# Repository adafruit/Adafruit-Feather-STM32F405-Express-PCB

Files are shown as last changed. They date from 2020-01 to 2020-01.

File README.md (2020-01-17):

## Adafruit Adafruit Feather STM32F405 Express PCB

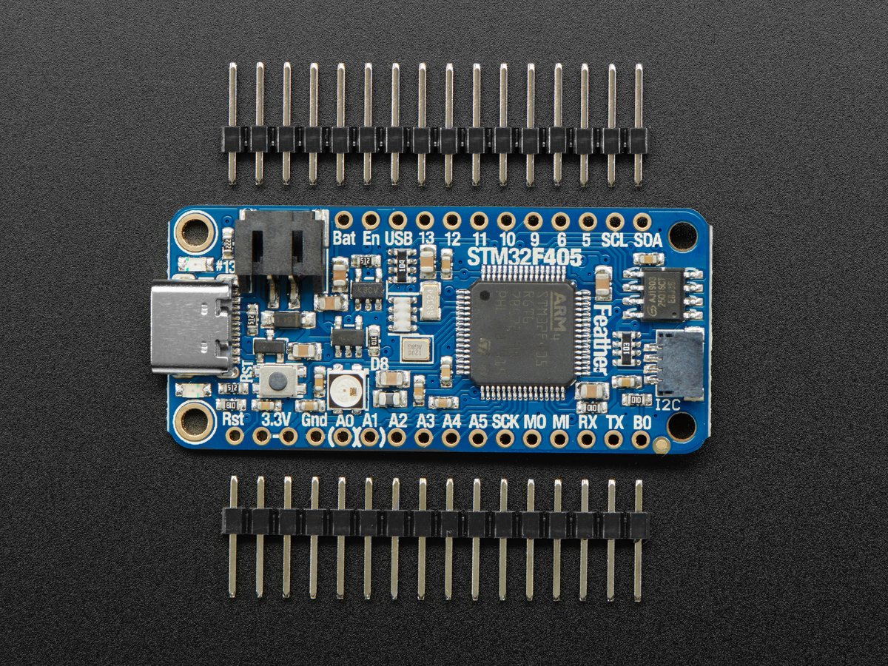
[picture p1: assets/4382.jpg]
<a href="http://www.adafruit.com/products/4382"><br/>
Click here to purchase one from the Adafruit shop</a>

PCB files for the Adafruit Adafruit Feather STM32F405 Express. 

Format is EagleCAD schematic and board layout
* https://www.adafruit.com/product/4382

### Description

ST takes flight in this upcoming Feather board. The new STM32F405 Feather (video) that we designed runs CircuitPython at a blistering 168MHz – our fastest CircuitPython board ever! We put a STEMMA QT / Qwiic port on the end, so you can really easily plug and play I2C sensors.

This Feather has lots of goodies:

* STM32F405 Cortex M4 with FPU and 1MB Flash, 168MHz speed
* 192KB RAM total - 128 KB RAM for general usage + 64 KB program-only/cache RAM
* 3.3V logic, but almost all pins are 5V compliant!
* USB C power and data - our first USB C Feather!
* LiPo connector and charger
* SD socket on the bottom, connected to SDIO port
* 2 MB SPI Flash chip
* Built in NeoPixel indicator
* I2C, UART, GPIO, ADCs, DACs
* Qwiic/STEMMA-QT connector for fast I2C connectivity
* We use the built-in USB DFU bootloader to load firmware. It does not come with a UF2 bootloader.

With CircuitPython basics running on this board, it's fast to get all our drivers working, then use the built in plotter in Mu to instantly get sensor data displaying within 3 minutes of unboxing.

You can use MicroPython, CircuitPython or Arduino IDE with this board, with some caveats. This board and chipset is new so expect rapid developments and updates!

* CircuitPython support is under development. We have digital IO, analog in/out, I2C, SPI, PWM working so far and more on the way. For example, the SDIO SD card is not yet supported natively. DisplayIO is also not yet supported.
* Arduino is supported through STM32duino. There's no auto-reset bootloader support yet so you have to pull the BOOT0 pin high and manually reset before uploading. That said, STM32 support is really good, and we were able to run just about every sketch we tried.
* MicroPython support is very solid but Adafruit does not provide MicroPython libraries for sensors!

We tested this in Arduino STM32duino with all our FeatherWings and only the RFM69/RFM9x libraries did not work (they are very platform specific). Its an extraordinarily fast Feather, and our first foray into STM32 - very exciting!

### License

Adafruit invests time and resources providing this open source design, please support Adafruit and open-source hardware by purchasing products from [Adafruit](https://www.adafruit.com)!

Designed by Limor Fried/Ladyada for Adafruit Industries.

Creative Commons Attribution/Share-Alike, all text above must be included in any redistribution. 
See license.txt for additional details.

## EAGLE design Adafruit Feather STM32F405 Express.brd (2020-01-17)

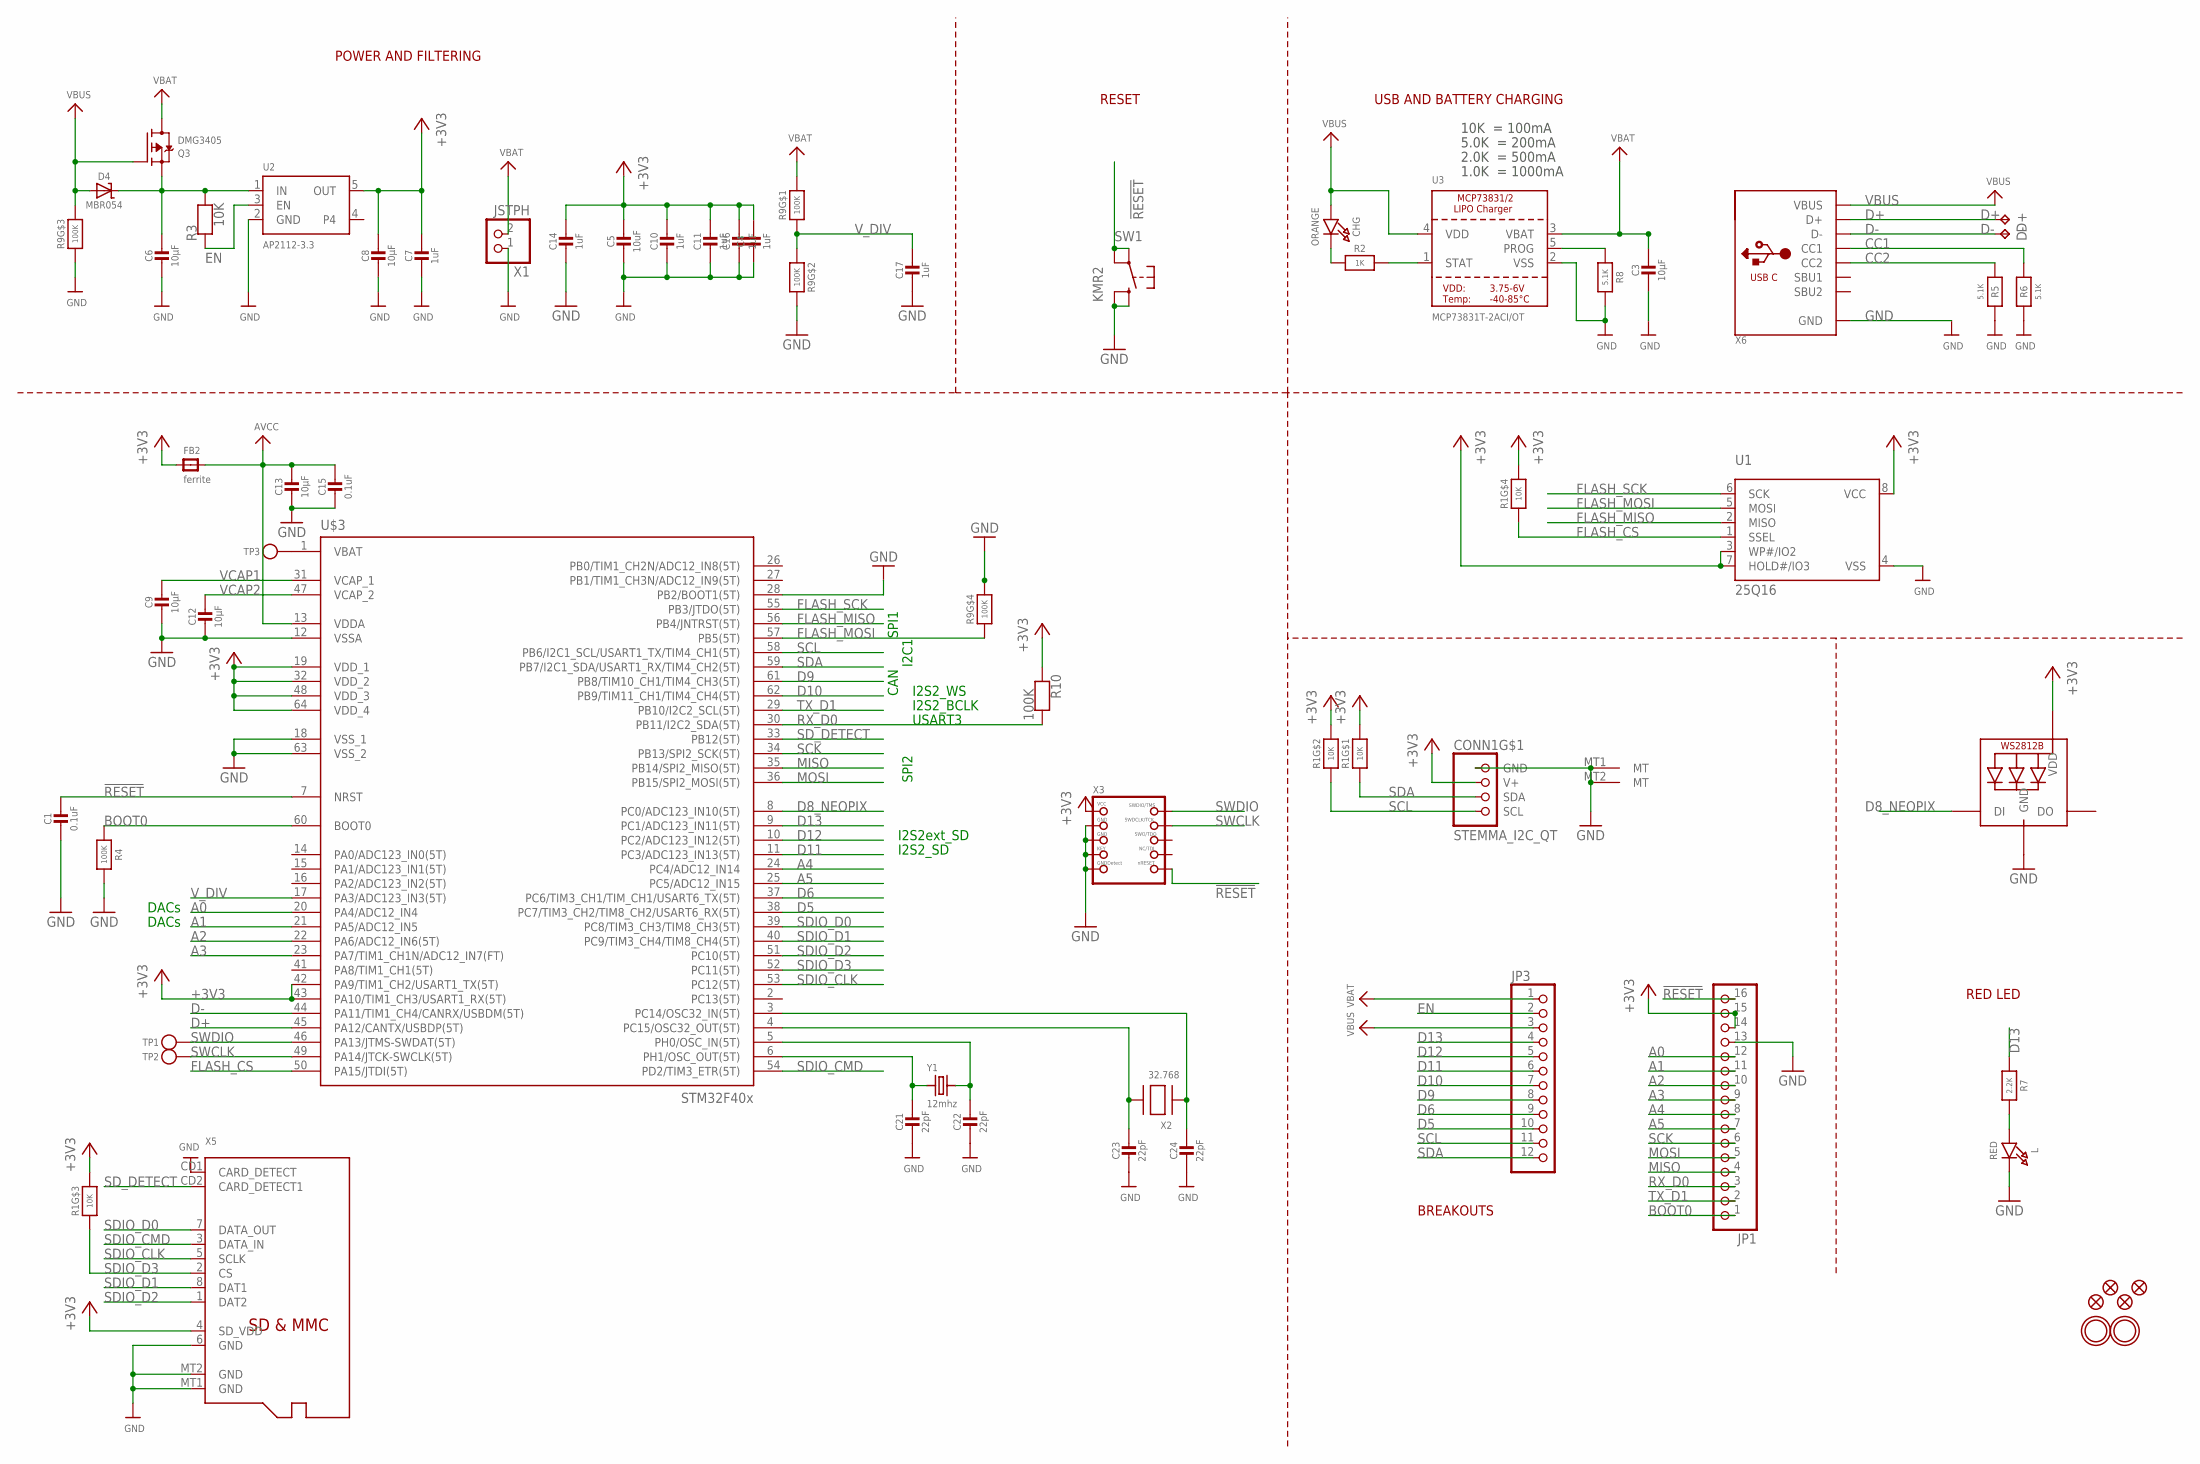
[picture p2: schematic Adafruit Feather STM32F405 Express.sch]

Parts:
C1, C15: 0.1uF; 0603-NO
C2: 22pF; RESPACK_4X0603
C3, C6, C8, C9, C12, C13: 10µF; 0805-NO
C4, C7, C10, C11, C14, C16, C17: 1uF; 0603-NO
C5: 10uF; 0805-NO
CHG: ORANGE; CHIPLED_0805_NOOUTLINE
CONN1: STEMMA_I2C_QT; JST_SH4
D4: MBR054; SOD-123
D+: TPB1,27; B1,27
D-: TPB1,27; B1,27
FB2: ferrite; 0805-NO
JP1: HEADER-1X16ROUND; 1X16_ROUND
JP3: HEADER-1X12; 1X12_ROUND
L: RED; CHIPLED_0805_NOOUTLINE
LED1: WS2812B3535; LED3535
Q3: DMG3405; SOT23-R
R1: 10K; RESPACK_4X0603_NO
R2: 1K; 0603-NO
R3: 10K; 0603-NO
R4, R10: 100K; 0603-NO
R5, R6, R8: 5.1K; 0603-NO
R7: 2.2K; 0603-NO
R9: 100K; RESPACK_4X0603_NO
SW1: KMR2; BTN_KMR2_4.6X2.8
TP1, TP2, TP3: TESTPOINTROUND1.5MM; TESTPOINT_ROUND_1.5MM
U1: 25Q16; SOIC8_150MIL
U2: AP2112-3.3; SOT23-5
U3: MCP73831T-2ACI/OT; SOT23-5
U$3: STM32F405R; TQFP64
U$5, U$34, U$35, U$37: FIDUCIAL_1MM
U$31, U$32: MOUNTINGHOLE2.5; MOUNTINGHOLE_2.5_PLATED
X1: JSTPH; JSTPH2
X2: 32.768; XTAL3215
X3: JTAG-CORTEX; 2X05_1.27MM_SMT
X5: MICROSD
X6: USB_C; USB_C_CUSB31-CFM2AX-01-X
Y1: 12mhz; CRYSTAL_2.5X2

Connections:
!RESET: C1.1, JP1.16, SW1.A, SW1.A' (P1), U$3.7 (NRST), X3.10 (NRESET)
+3V3: C4.1, C5.1, C7.1, C8.1, C10.1, C11.1, C14.1, C16.1, CONN1.2 (V+), FB2.1, JP1.14, JP1.15, LED1.2 (VDD), R1.5 (2), R1.6 (2), R1.7 (2), R1.8 (2), R10.1, U1.3 (WP#/IO2), U1.7 (HOLD#/IO3), U1.8 (VCC), U2.5 (OUT), U$3.19 (VDD_1), U$3.32 (VDD_2), U$3.42 (PA9/TIM1_CH2/USART1_TX(5T)), U$3.43 (PA10/TIM1_CH3/USART1_RX(5T)), U$3.48 (VDD_3), U$3.64 (VDD_4), X3.1 (VCC), X5.4 (SD_VDD)
A0: JP1.12, U$3.20 (PA4/ADC12_IN4)
A1: JP1.11, U$3.21 (PA5/ADC12_IN5)
A2: JP1.10, U$3.22 (PA6/ADC12_IN6(5T))
A3: JP1.9, U$3.23 (PA7/TIM1_CH1N/ADC12_IN7(FT))
A4: JP1.8, U$3.24 (PC4/ADC12_IN14)
A5: JP1.7, U$3.25 (PC5/ADC12_IN15)
AVCC: C13.1, C15.1, FB2.2, U$3.13 (VDDA)
BATTERY: TP3.P$1, U$3.1 (VBAT)
BOOT0: JP1.1, R4.1, U$3.60 (BOOT0)
CC1: R6.2, X6.A5 (CC1)
CC2: R5.2, X6.B5 (CC2)
D5: JP3.10, U$3.38 (PC7/TIM3_CH2/TIM8_CH2/USART6_RX(5T))
D6: JP3.9, U$3.37 (PC6/TIM3_CH1/TIM_CH1/USART6_TX(5T))
D8_NEOPIX: LED1.1 (DI), U$3.8 (PC0/ADC123_IN10(5T))
D9: JP3.8, U$3.61 (PB8/TIM10_CH1/TIM4_CH3(5T))
D10: JP3.7, U$3.62 (PB9/TIM11_CH1/TIM4_CH4(5T))
D11: JP3.6, U$3.11 (PC3/ADC123_IN13(5T))
D12: JP3.5, U$3.10 (PC2/ADC123_IN12(5T))
D13: JP3.4, R7.1, U$3.9 (PC1/ADC123_IN11(5T))
D+: D+.TP, U$3.45 (PA12/CANTX/USBDP(5T)), X6.A6 (D+), X6.B6 (D+)
D-: D-.TP, U$3.44 (PA11/TIM1_CH4/CANRX/USBDM(5T)), X6.A7 (D-), X6.B7 (D-)
EN: JP3.2, R3.1, U2.3 (EN)
FLASH_CS: R1.4 (1), U1.1 (SSEL), U$3.50 (PA15/JTDI(5T))
FLASH_MISO: U1.2 (MISO), U$3.56 (PB4/JNTRST(5T))
FLASH_MOSI: R9.4 (1), U1.5 (MOSI), U$3.57 (PB5(5T))
FLASH_SCK: U1.6 (SCK), U$3.55 (PB3/JTDO(5T))
GND: C1.2, C2.5 (2), C2.6 (2), C2.7 (2), C2.8 (2), C3.2, C4.2, C5.2, C6.2, C7.2, C8.2, C9.2, C10.2, C11.2, C12.2, C13.2, C14.2, C15.2, C16.2, C17.2, CONN1.1 (GND), CONN1.MT1 (MT), CONN1.MT2 (MT), JP1.13, L.C, LED1.4 (GND), R4.2, R5.1, R6.1, R8.2, R9.3 (1), R9.5 (2), R9.7 (2), SW1.B (S), SW1.B' (S1), U1.4 (VSS), U2.2 (GND), U3.2 (VSS), U$3.12 (VSSA), U$3.18 (VSS_1), U$3.28 (PB2/BOOT1(5T)), U$3.63 (VSS_2), X1.1, X3.3 (GND), X3.5 (GND), X3.7 (KEY), X3.9 (GNDDETECT), X5.6 (GND), X5.CD1 (CARD_DETECT), X5.MT1 (GND), X5.MT2 (GND), X6.A1B12 (GND), X6.B1A12 (GND)
MISO: JP1.4, U$3.35 (PB14/SPI2_MISO(5T))
MOSI: JP1.5, U$3.36 (PB15/SPI2_MOSI(5T))
unnamed: CHG.C, R2.1
unnamed: L.A, R7.2
unnamed: R2.2, U3.1 (STAT)
unnamed: R8.1, U3.5 (PROG)
unnamed: C2.4 (1), U$3.3 (PC14/OSC32_IN(5T)), X2.P$1
unnamed: C2.2 (1), U$3.5 (PH0/OSC_IN(5T)), Y1.3 (2)
unnamed: C2.3 (1), U$3.4 (PC15/OSC32_OUT(5T)), X2.P$2
unnamed: C2.1, U$3.6 (PH1/OSC_OUT(5T)), Y1.1
RX_D0: JP1.3, R10.2, U$3.30 (PB11/I2C2_SDA(5T))
SCK: JP1.6, U$3.34 (PB13/SPI2_SCK(5T))
SCL: CONN1.4 (SCL), JP3.11, R1.2 (1), U$3.58 (PB6/I2C1_SCL/USART1_TX/TIM4_CH1(5T))
SDA: CONN1.3 (SDA), JP3.12, R1.1, U$3.59 (PB7/I2C1_SDA/USART1_RX/TIM4_CH2(5T))
SDIO_CLK: U$3.53 (PC12(5T)), X5.5 (SCLK)
SDIO_CMD: U$3.54 (PD2/TIM3_ETR(5T)), X5.3 (DATA_IN)
SDIO_D0: U$3.39 (PC8/TIM3_CH3/TIM8_CH3(5T)), X5.7 (DATA_OUT)
SDIO_D1: U$3.40 (PC9/TIM3_CH4/TIM8_CH4(5T)), X5.8 (DAT1)
SDIO_D2: U$3.51 (PC10(5T)), X5.1 (DAT2)
SDIO_D3: R1.3 (1), U$3.52 (PC11(5T)), X5.2 (CS)
SD_DETECT: U$3.33 (PB12(5T)), X5.CD2 (CARD_DETECT1)
SWCLK: TP2.P$1, U$3.49 (PA14/JTCK-SWCLK(5T)), X3.4 (SWDCLK)
SWDIO: TP1.P$1, U$3.46 (PA13/JTMS-SWDAT(5T)), X3.2 (SWDIO)
TX_D1: JP1.2, U$3.29 (PB10/I2C2_SCL(5T))
VBAT: C3.1, JP3.1, Q3.3 (D), R9.8 (2), U3.3 (VBAT), X1.2
VBUS: CHG.A, D4.A, JP3.3, Q3.1 (G), R9.6 (2), U3.4 (VDD), X6.A4B9 (VBUS), X6.B4A9 (VBUS)
VCAP1: C9.1, U$3.31 (VCAP_1)
VCAP2: C12.1, U$3.47 (VCAP_2)
VHI: C6.1, D4.C, Q3.2 (S), R3.2, U2.1 (IN)
V_DIV: C17.1, R9.1, R9.2 (1), U$3.17 (PA3/ADC123_IN3(5T))

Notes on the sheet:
POWER AND FILTERING
RESET
10K = 100mA
5.0K = 200mA
2.0K = 500mA
1.0K = 1000mA
USB AND BATTERY CHARGING
BREAKOUTS
RED LED
SPI1
SPI2
USART3
DACs
I2C1
I2S2_WS
I2S2_BCLK
I2S2_SD
I2S2ext_SD
CAN

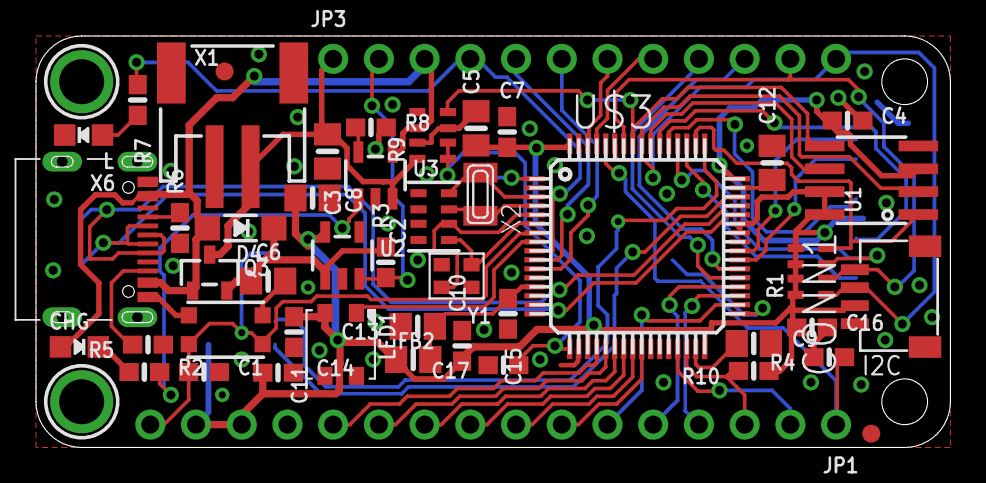
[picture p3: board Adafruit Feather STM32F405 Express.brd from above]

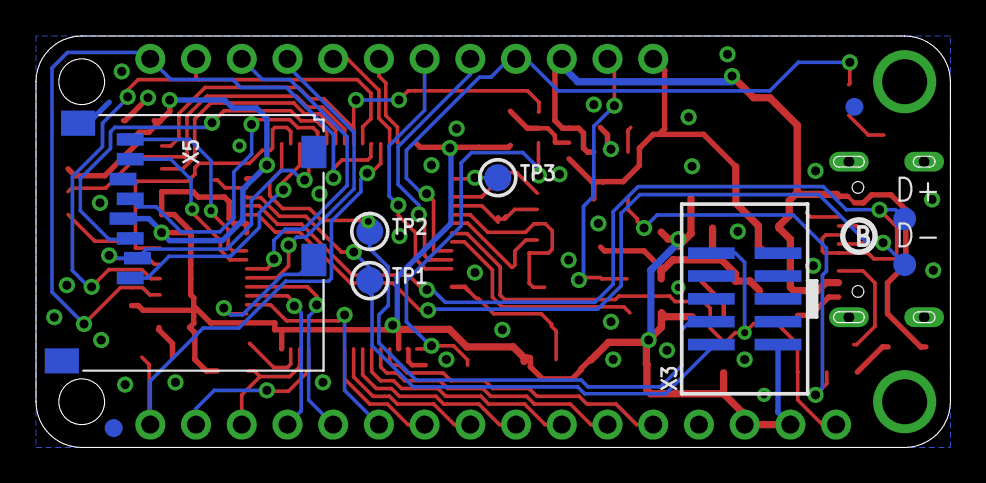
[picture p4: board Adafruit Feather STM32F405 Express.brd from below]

Board: 2 copper layers, 50.8 x 22.9 mm, 61 parts (11 on the bottom side), 59 nets.

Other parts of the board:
U$13: PCBFEAT-REV-040
U$24: FEATHER_STM32F405_TOP
U$40: FEATHER_STM32F405_BOT

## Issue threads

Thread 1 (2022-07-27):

STM32F405 Express, PCB error about SD card detection

dombru54, 2022-07-27:
Hello,

With your STM32F405 Feather Express card, the PB12 pin (cardDetect) is always to 0 (GND).
This is due to a short circuit with the card reader double pin 10
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

Error in the card reader manufacturer's datasheet and red correction
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

With actual PCB, cut ground track with a scalpel, at the edge of the metal case
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

Thanks to make a revision of this board
.

ladyada, 2022-07-27:
thanks for the note - we'll fix this on the next PCB run!

dombru54, 2022-07-27:
Sorry,
The new schema corrected
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

javiBajoCero, 2023-04-13:
Howdy @dombru54 , thanks for your work, i just purchased two feathers from [here](https://www.berrybase.de/es/adafruit-feather-stm32f405-express), and i foudn the same problem with the same solution.

I dont see any Hardware revision markings in my boards, so either berrybase had old stock or this error wasnt fixed yet.

dombru54, 2023-04-14:
@javiBajoCero ,
It is with great pleasure that I welcome your return, my friend.
I also invite you to see another of my work on the Oled feather
https://github.com/adafruit/Adafruit-OLED-FeatherWing-PCB/issues/10
Best regards

dombru54, 2023-04-14:
@javiBajoCero ,
In addition, if you work with STM32CubeIDE, you must modify :
".....\STM32CubeIDE\workspace_1.8.0\project\FATFS\Target\fatfs_platform.c"
````
uint8_t	BSP_PlatformIsDetected(void) {
    uint8_t status = SD_PRESENT;
    /* Check SD card detect pin */
    if(HAL_GPIO_ReadPin(SD_DETECT_GPIO_PORT, SD_DETECT_PIN) != GPIO_PIN_RESET)
    {
        status = SD_NOT_PRESENT;
    }
    /* USER CODE BEGIN 1 */
    /* user code can be inserted here */
    // Correction de l'erreur génèrée dans le code par MX, au dessus
    if(HAL_GPIO_ReadPin(SD_DETECT_GPIO_PORT, SD_DETECT_PIN) == GPIO_PIN_SET){	// carte présente = 1 (SET)
    	status = SD_PRESENT;
    }
    /* USER CODE END 1 */
    return status;

javiBajoCero, 2023-04-14:
Thanks for your advice, i was trying to make SD+SDIO(4bits) work but, two days later, still nothing.

Not STM32 HAL CUbeMX based, not even with arduino
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

I know statistically im messing up something in my code but seeing they missed this SD detection Gpio, im starting to be afraid they didnt tested SD .

If you have any more clues or repos with working code let me know

dombru54, 2023-04-14:
@javiBajoCero ,
All the SDIO 4 bits mode works on the Feather ! but ....
"two days later, still nothing." .... normal ... ;>) .... SDIO is very poorly documented.
I struggled for more than a week before having all the elements !!!
1) SDIO clock is based on USB clock at 48MHz.
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

2) After, you must use a divider with ClockDiv = 3 , especially not another value ... for me
   SDIO_CK = SDIOCLK / (2 + CLKDIV) => SDIO_CK = 48MHz/(2+3) = 9.6 MHz
````
  static void MX_SDIO_SD_Init(void) {
  hsd.Instance = SDIO;
  hsd.Init.ClockEdge = SDIO_CLOCK_EDGE_RISING;
  hsd.Init.ClockBypass = SDIO_CLOCK_BYPASS_DISABLE;
  hsd.Init.ClockPowerSave = SDIO_CLOCK_POWER_SAVE_DISABLE;
  hsd.Init.BusWide = SDIO_BUS_WIDE_1B;
  hsd.Init.HardwareFlowControl = SDIO_HARDWARE_FLOW_CONTROL_DISABLE;
  hsd.Init.ClockDiv = 3; }
````

dombru54, 2023-04-15:
@javiBajoCero ,

3) For good precision, it is more than recommended to use the 2 quartz, therefore the 2 LSE and HSE modes.
````
void SystemClock_Config(void) {
  .......
  RCC_OscInitStruct.OscillatorType = RCC_OSCILLATORTYPE_HSE|RCC_OSCILLATORTYPE_LSE;
  RCC_OscInitStruct.HSEState = RCC_HSE_ON;
  RCC_OscInitStruct.LSEState = RCC_LSE_ON;
  RCC_OscInitStruct.PLL.PLLState = RCC_PLL_ON;
  RCC_OscInitStruct.PLL.PLLSource = RCC_PLLSOURCE_HSE;
  .......

dombru54, 2023-04-15:
@javiBajoCero ,
Feather has a trap about its serigraphy, 2 "Bats" with 2 different functions, one for powering on LiPo connector and the other on backing up the RTC.
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

dombru54, 2023-04-15:
@javiBajoCero ,
4. For the SDIO to work, you must activate the USB pins.
    Here is the complete pinout of my cubeMX project : My sensors board is FlowMotion Breakout on I2C and SPI.
    Magenta pins => not connected to the PCB.
    Orange pins => declared but not used

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

javiBajoCero, 2023-04-15:
Hi @dombru54 , first thanks for all of your tips, they are gold!

I got it to work yesterday, my problems were ;
- the clock divider was too low (resulting SDIO clokc was too fast)
- the SD detect logic needded to be reversed
- fatfs library doesnt like to be breakpointed by the debugger.

About your tips:

1. SDIO clock is based on USB clock at 48MHz.

I see youre using a super old version of cubeMX, why is that?
>In my Cube version i cannot se any SDIO dedicated box in the clock graphic config tool.
I tought the SDIO  was clocked with the APB2 peripheral clock.
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
i am not enabling the USB and SDIO works as expected.

2.After, you must use a divider with ClockDiv = 3 , especially not another value ... for me
>bingo, this was one of the problems i had, apparently SDIO really dislikes being clocked further than 24Mhz
as my APB2 is clocked to 84Mhz by using a divide factor of 4 i get 14Mhz for the SDIO and it works.
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

3.For good precision, it is more than recommended to use the 2 quartz, therefore the 2 LSE and HSE modes.
>I had this present since the start, always HSE (xtal), my last job consisted in 2 painfull years of mitigating the cathastrophic decision someone had using a HSI for automotive CANbus connected systems. (because it worked for them in the lab)

4.4. For the SDIO to work, you must activate the USB pins, maybe to run USB clock.
>Thanks for sharing your design!, i didnt need to enable the USB for my progect to work tough, check it out in here https://github.com/javiBajoCero/featherSDcardTests

dombru54, 2023-04-15:
Hello @javiBajoCero ,
Thanks for sharing your experience.

1. I don't have an old version, it's a copy of web image ... ;>) ...
   the "Clock configuration" is not complete, it lacks sharing modes between HSE and LSE, for example ... but also SDIO clock ...

2. I'm happy for you, Thanks for RM0090, but i'm surprised.
page 1022 :
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

3. HSE is also very important for the PDM bus with microphones (ultrasonic acoustic spectrum aliasing of decimation).

4. Thank you for this surprising information.

Hope to read you soon

dombru54, 2023-04-15:
Hello @javiBajoCero ,

1. see AN3988 : https://www.st.com/resource/en/application_note/an3988-clock-configuration-tool-for-stm32f40xx41xx427x437x-microcontrollers-stmicroelectronics.pdf
   see "Clock configuration tool" STSW-STM32091 : https://www.st.com/en/development-tools/stsw-stm32091.html
   it's an Excel sheet : "STM32F4xx_Clock_Configuration_V1.1.0.xls"

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

SYL

javiBajoCero, 2023-04-16:
Its my first time working with stm32's F4 family, so i was just clicking my way with cubeMx doing all the clock configs.

SDIO is indeed very poorly documented.
It seems SDIO uses indeed two different clocks comming from two different places, one for the APB interface and another for the "adapter".
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

1. see AN3988
>So my guess is , cubeMX is enabling the SDIOCLK somwhere for me.
No clue of where **PLL48CLK** is, there is a lack of consistent naming in these stm ap notes.
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
It looks to me , somewhere, there is a PLL48CLK from which USB and SDIO clocks would come from, USB would only work with sharp 48Mhz so if enabled, all the rest of peripherals whose clock comes from PLL48CLK  will need to work with 48Mhz as well.
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

dombru54, 2023-04-16:
Hello @javiBajoCero ,
In one of your repo first page, you can add our sharing ... a gold mine .... ;>) ...
SYL

dombru54, 2023-04-16:
Hello @javiBajoCero ,
if you like "Feather factor form", you must absolutely see the great "Swan Blues Wireless", STM32L4R5 :
https://blues.io/products/swan/
https://www.hackster.io/news/swan-from-blues-wireless-is-the-most-expandable-feather-compatible-board-to-date-01132f5a0a91
https://github.com/gauteh/swan-stm32l4r5-quickstart
https://blog.adafruit.com/2021/09/30/the-blues-wireless-swan-a-feather-board-based-on-the-stm32l4r5-feather-blueswireless/

Version 1.7 :
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
Multi-layers board, V1.7, it exists Version 3.0 :
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

javiBajoCero, 2023-04-16:
>In one of your repo first page, you can add our sharing ... a gold mine .... ;>) ...

I didnt understood that sorry.

>"Swan Blues Wireless"

this looks very nice!!! i will stick with adafruit feather tough.
I just wanted some hardware to test my code before spending money manufacturing my own thing.

dombru54, 2023-04-16:
Hello @javiBajoCero ,
In one of your repo first page, you can add our sharing ... a gold mine .... ;>) ...

Sorry, most directly, you could insert this issue in the file "readme.md" of https://github.com/javiBajoCero/featherSDcardTests ...
This might help a reader of your repo.

Neopixel ... I understand why : https://www.hackster.io/javier-munoz-saez/coding-your-own-neopixel-driver-baremetal-stm32-b6b4d0
SYS

aspence, 2023-11-28:
Hi all!

Trying to use the SD card on this board over SDIO within ST32duino. We can program the board and get data from an MSA311 over the qic connect, but we can't get SD.begin() to work. Initially, it would hang for a long time at this step (multiple seconds), and then fail. We think we found the letter "B" with a circle around it on the board, suggesting this was a Rev B board with the card detect trace error. We cut that trace with an exacto. Now, it fails much more quickly. Our hypotheses as to the problem are:

1. We are not initializing the library correctly
2. We are not formatting the SD card correctly
3. There is still a wiring error.

Details of each are:
1. Our code is along the lines of
#include <STM32SD.h>

setup:
SD.setDX(PC8,PC9,PC10,PC11);
SD.setCK(PC12);
SD.setCMD(PD2);
if (!SD.begin(PB12)) {  // detect
  Serial.println('failure to init');
  while(1);
}

we are not including a PinName library - but it compiles so I assume that's ok...

2. We have a 120gb SD card. In windows, we erased all partitions and created a single 3.5 gb fat32 partition. we did not alter the partition table.

3. The fact that the boot time/error time changed after we cut the trace suggested it did something, but it still gives an error on startup. We dont have a known good SD card around to try.

It would be very useful to hear from anyone who has gotten this working with code similar to the above for setting the pins, and with just cutting the trace.

If we need to mess with changing things in libraries or adjusting clock timings, then i think we'll just stack an adalogger feather wing on it and communicate with the SD card via SPI or something simpler.

Thank you for any input!

dombru54, 2023-11-29:
Hello,

First, verify PB12 pin (cardDetect) with voltmeter.

Sorry, i don't know STM32duino, i just use STM32codeIDE.
Maybe, you must modify a part of your library ... (insert correction code between user code balises) as this :

".....\STM32CubeIDE\workspace_1.8.0\project\FATFS\Target\fatfs_platform.c"
~~~
uint8_t	BSP_PlatformIsDetected(void) {
    uint8_t status = SD_PRESENT;
    /* Check SD card detect pin */
    if(HAL_GPIO_ReadPin(SD_DETECT_GPIO_PORT, SD_DETECT_PIN) != GPIO_PIN_RESET)
    {
        status = SD_NOT_PRESENT;
    }
    /* USER CODE BEGIN 1 */
    /* user code can be inserted here */
    // Correction de l'erreur génèrée dans le code par MX, au dessus
    if(HAL_GPIO_ReadPin(SD_DETECT_GPIO_PORT, SD_DETECT_PIN) == GPIO_PIN_SET){	// carte présente = 1 (SET)
    	status = SD_PRESENT;
    }
    /* USER CODE END 1 */
    return status;
~~~

timurkelin, 2024-10-06:
Hi @javiBajoCero,

Did you finally manage to make the SD card work?

I'm at the same standpoint and started the discussion in here:
https://forums.adafruit.com/viewtopic.php?p=1031343#p1031343

javiBajoCero, 2024-10-07:
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

yup, i managed
https://github.com/javiBajoCero/featherSDcardTests

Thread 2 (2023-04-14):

Did anyone made the SD card work?

javiBajoCero, 2023-04-14:
Hi , i have succesfully developed SD+SPI with stm32 boards (HAL baremetal) in the past.

But never with SDIO, thats why i purchased a couple of stm32f405 express boards.
This is my setup: STLINK from a nucleo connected to the feather board.
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

With Stm32CubeIDE: (HAL C)
I am not able to make the diskio to talk with the SD card, as if there was no SD card all along.

With Arduino: (C++)
similar error,
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

Before diving in hardcore bleedy debugging, and acknowleding this board is a bit niche with almost noone using it.
**Did anyone made the SD card work?**

javiBajoCero, 2023-04-14:
I made it work following that digikey tutorial, and reversing the GPIO logic in the SD detect pin https://github.com/javiBajoCero/featherSDcardTests

javiBajoCero, 2023-04-14:
I made it work following that digikey tutorial, and reversing the GPIO logic in the SD detect pin https://github.com/javiBajoCero/featherSDcardTests

Closed 2023-04-14.

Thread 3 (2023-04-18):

How are you driving pin D8's neopixel¿?

javiBajoCero, 2023-04-18:
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
there is no PWM nor SPI functions available, are you bitbanging the protocol? 800Khz?

The board came factory programmed with arduino sketches and the D8's neopixel was working.
I suppose this library is used https://github.com/adafruit/Adafruit_NeoPixel ?
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
Yes they are.

They are introducing empty assembly instructions as wait spaces 👯‍♂️, this is how it works:
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

javiBajoCero, 2023-04-18:
so yes bitbanging, if it were up to me i would reroute D8(no pwm) to PA0 (TIM2_CH1 PWM).

As for me, llbe using one of the free PWM pins with some external neopixel stripes.

Closed 2023-04-18.

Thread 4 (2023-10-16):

JST-PH Polarity

mikeysklar, 2023-10-16:
Adafruit battery packs have consistent polarity. Third party batteries not so much. Silkscreen of + and - near the battery JST-PH connector would help avoid blow out.

The RP2040 and Micro Lipo USB charger are two examples of Adafruit products that already do this.

https://forums.adafruit.com/viewtopic.php?t=205204

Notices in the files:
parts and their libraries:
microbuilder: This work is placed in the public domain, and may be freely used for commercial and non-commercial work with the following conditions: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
